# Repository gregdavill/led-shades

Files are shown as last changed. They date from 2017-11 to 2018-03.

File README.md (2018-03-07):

# ledShades

*Simple Arduino compatible RGB LED shades. Using an absurd quantinty of APA102 2020 smart LEDs.*

## 3d Render

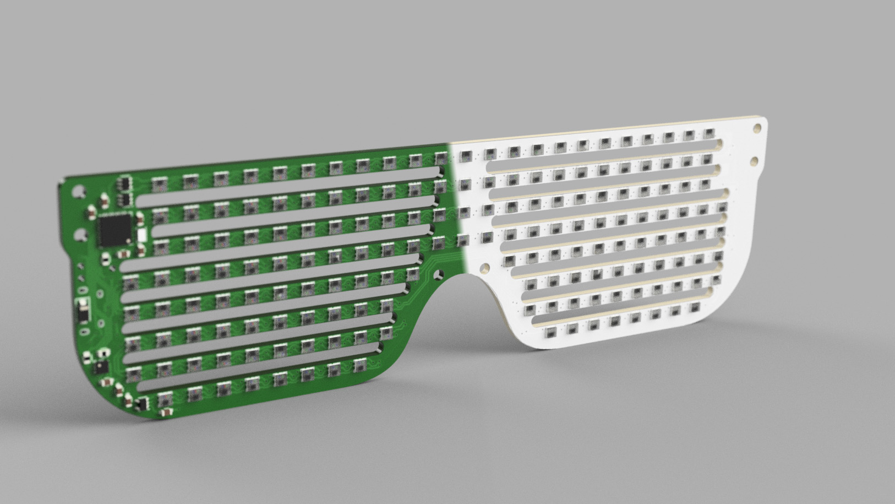
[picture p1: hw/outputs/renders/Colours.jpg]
led-shades Render


When deciding between green and white PCBs I created this render. I ended up using white PCBs for my prototypes. Black would also look good.

---

## Schematic

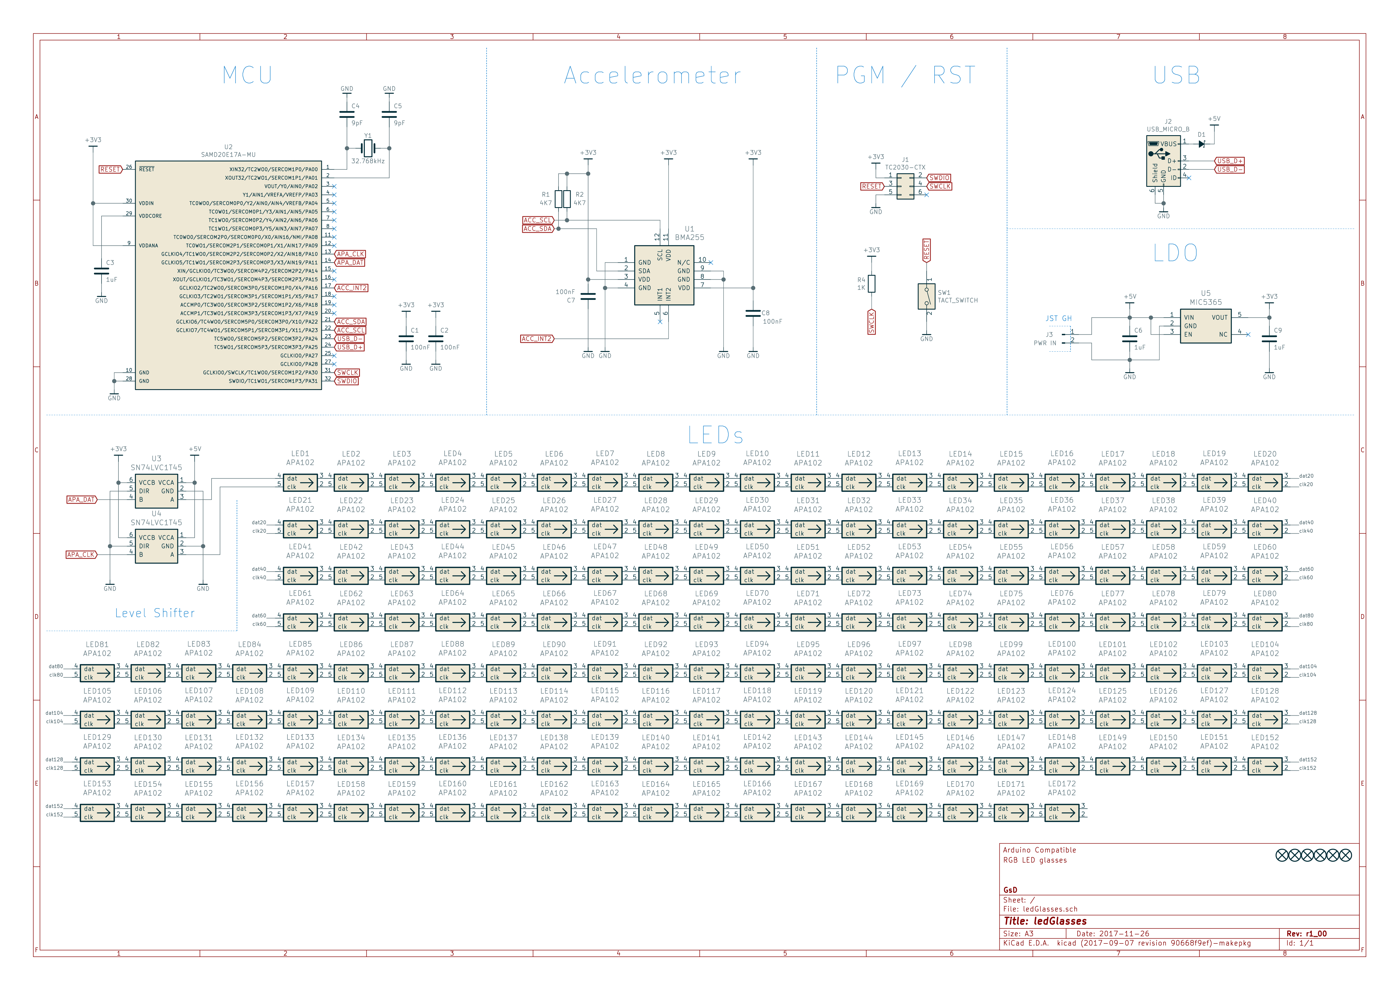
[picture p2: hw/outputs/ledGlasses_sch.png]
led-shades Schematic


Schematic is quite simple. The ATSAMD21 is loaded with the Arduino bootloader and programmed with FastLED to control the single array of 173 APA102 LEDs. Due to the voltage difference between the D21 and the APA102's I used two logic level converters for the clock and data lines.

---

## PCB

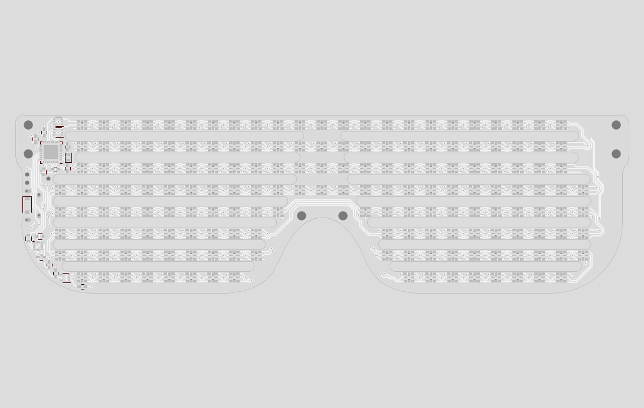
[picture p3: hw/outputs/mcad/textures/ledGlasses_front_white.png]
led-shades PCB


PCB was designed in KiCad and is a mostly single sided load. (Power connector, solders to back). The PCB is designed to act as the frame of the glasses directly. Some 3d printed arms are fitted to the edges of the glasses in older to attach them to your face.

---

## Firmware

The firmawre for the device is found in the fw folder. It is buil/t with the arduino IDE with 2 external libraries

* Adafruit GFX
* FastLED

The included code provides a simple wrapper to connect these libraries together to control the screen. Some small changes need to be made in orlder to accomadate good quality RGB data to the LEDs this includes changing the colour parameter in the GFX library to uint32_t type.

The main code supports 4 different modes of operation. Switching between modes is achieved by tapping the right side of the glasses. This triggers a tap event with the accelorometer.

## Development Timeline

* [x] Concept
* [x] Schematic
* [x] PCB Layout
* [x] 3d CAD export/cleanup
* [x] BOM export
* [x] Prototypes assembled
* [x] Firmware buildup
* [x] Additional Documentation
* [x] Small Volume Run

## License

MIT - See [LICENCE](LICENSE)

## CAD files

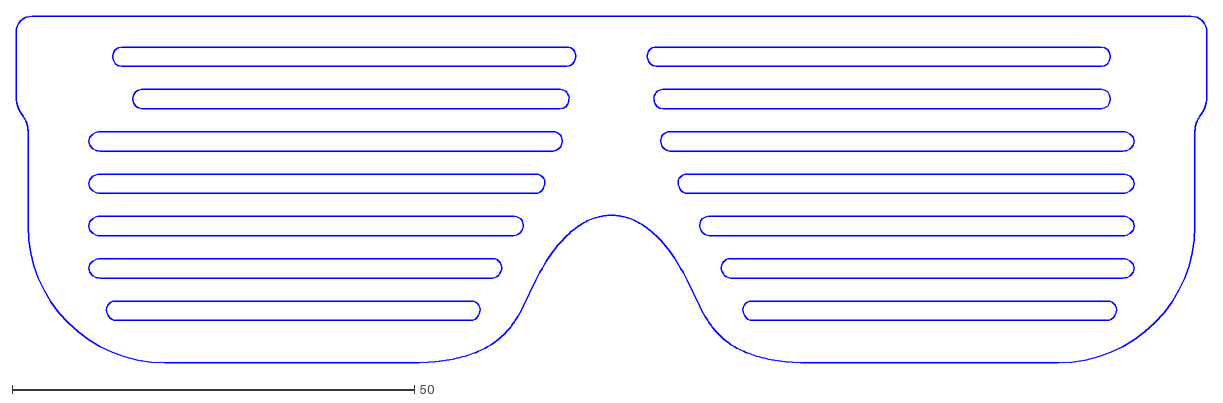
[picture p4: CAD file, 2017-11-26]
hw/ref/PCB outline.dxf
148.1 x 43.1

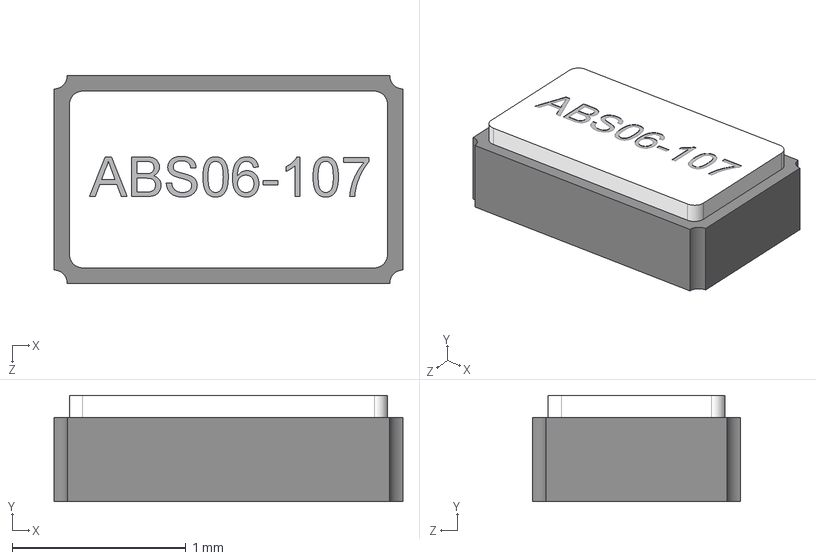
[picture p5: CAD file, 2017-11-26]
hw/ref/ABS06-107.STEP
2.01 x 0.612 x 1.19 mm

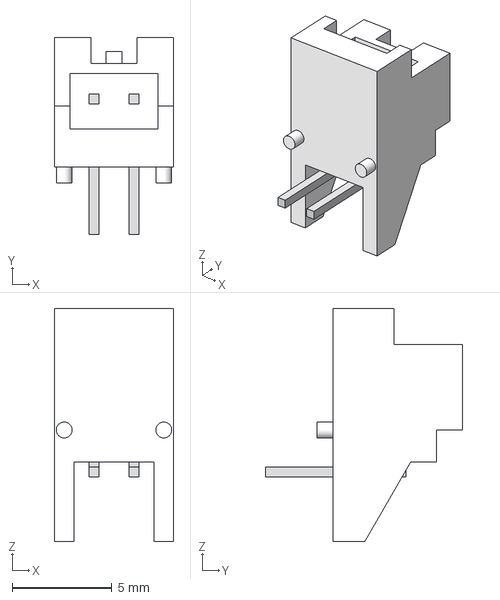
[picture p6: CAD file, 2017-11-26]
hw/ref/S02B-PASK-2.step
6.00 x 9.90 x 11.7 mm

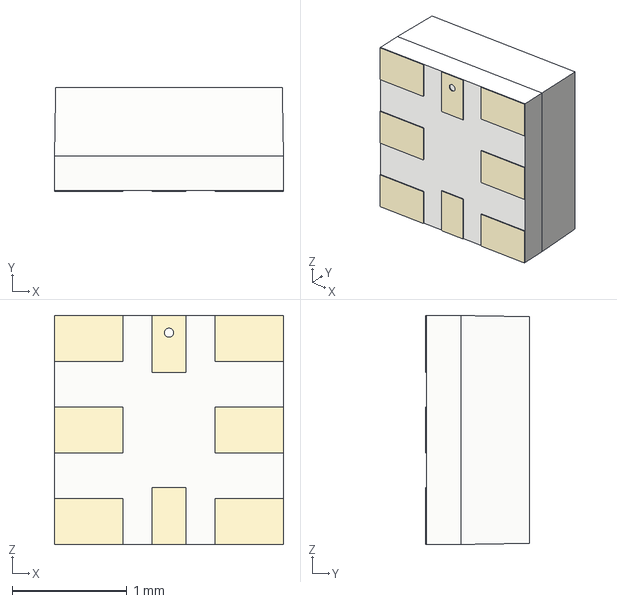
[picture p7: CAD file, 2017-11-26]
hw/ref/APA102 2020 LED.step
2.00 x 0.91 x 2.00 mm

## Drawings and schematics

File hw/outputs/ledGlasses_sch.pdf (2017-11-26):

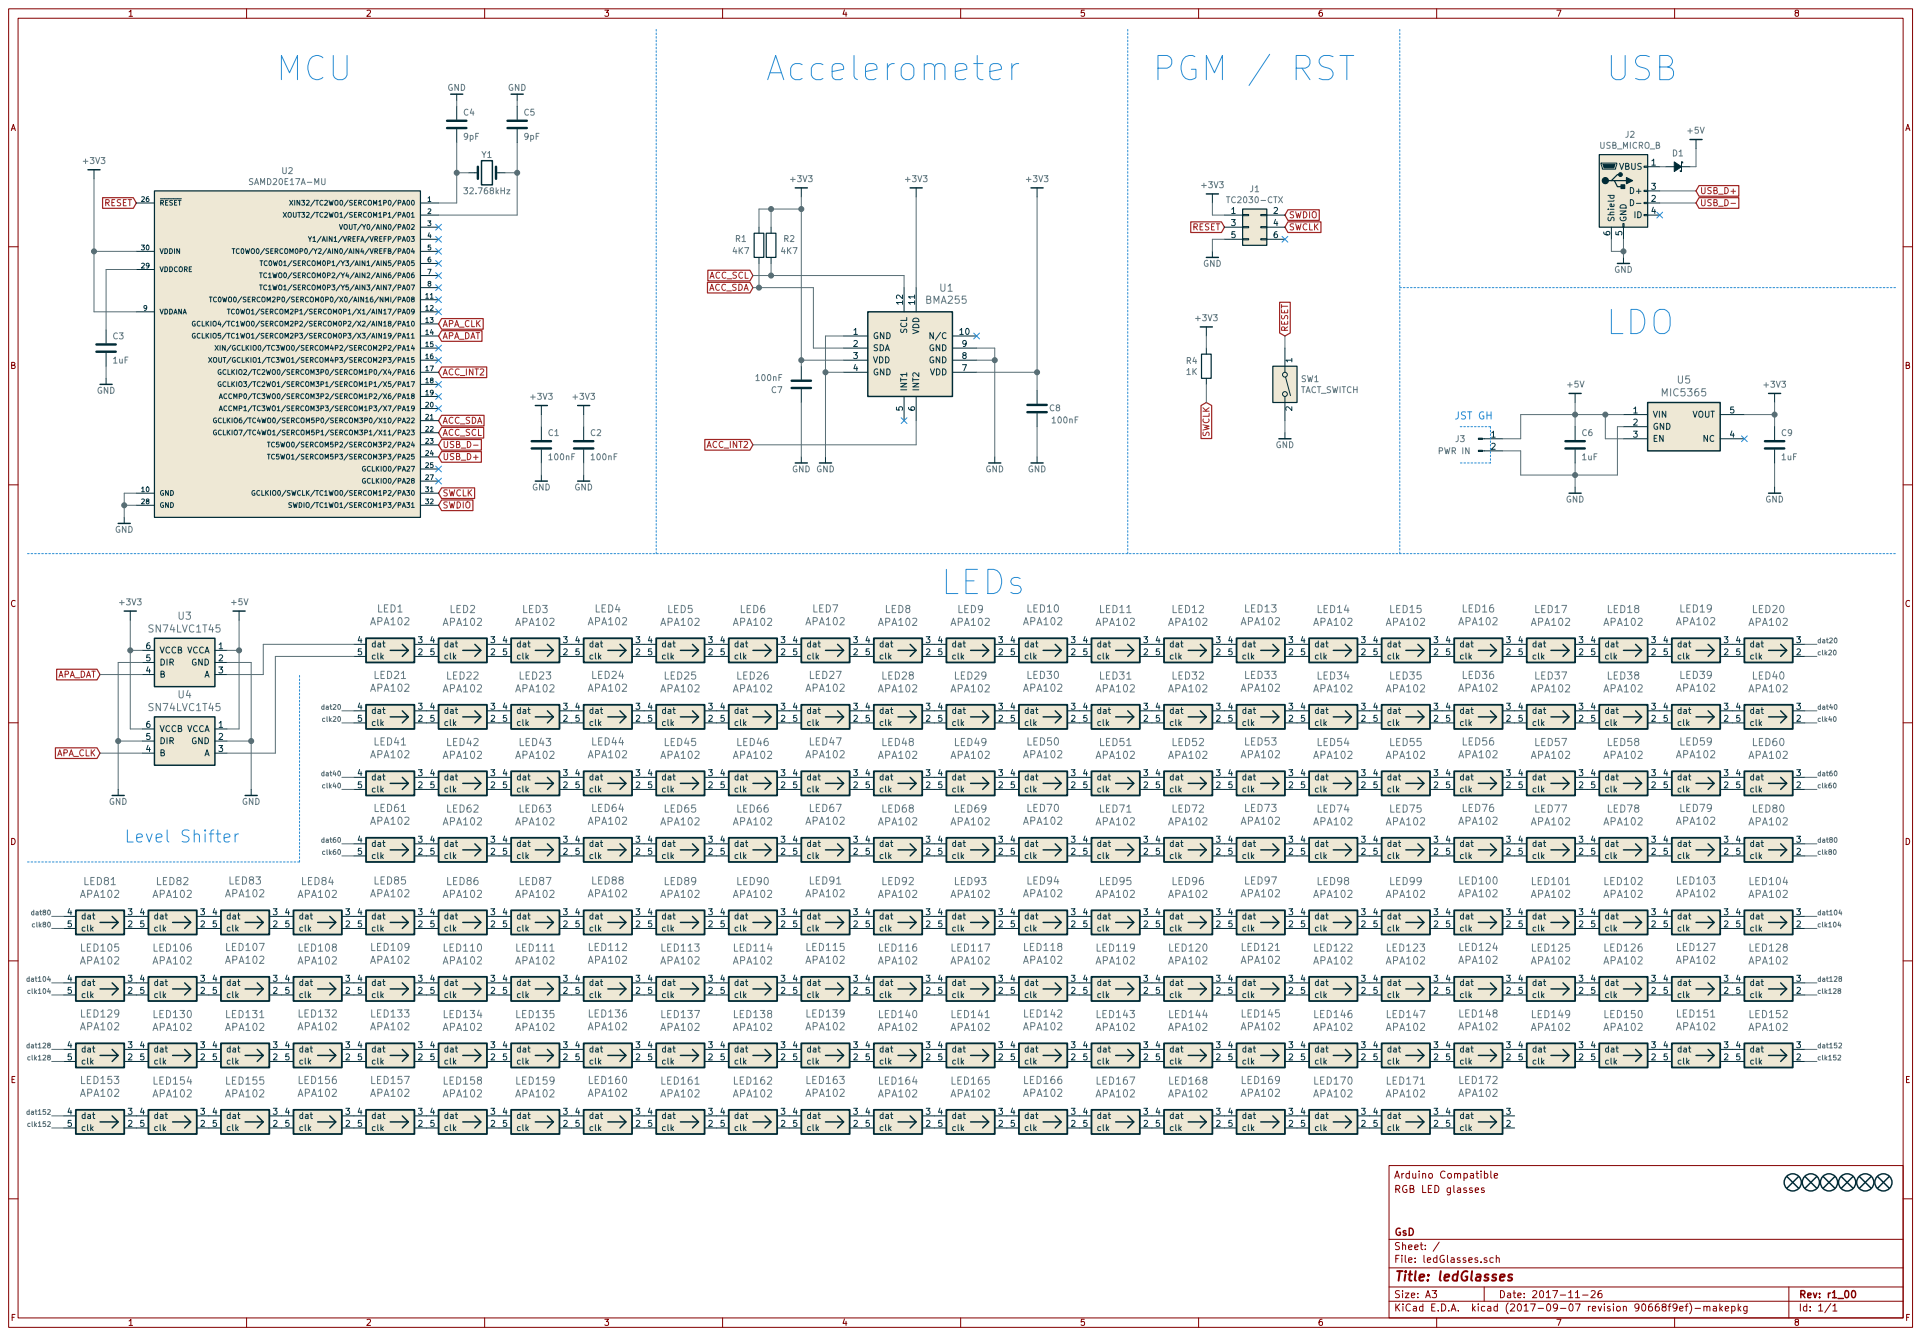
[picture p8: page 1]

6 VDD 7 GND 8 GND 9 N/C VDD 10 11 SCL 12 U1 BMA255

J3 PWR IN Level Shifter

File: ledGlasses.sch Sheet: / GsD

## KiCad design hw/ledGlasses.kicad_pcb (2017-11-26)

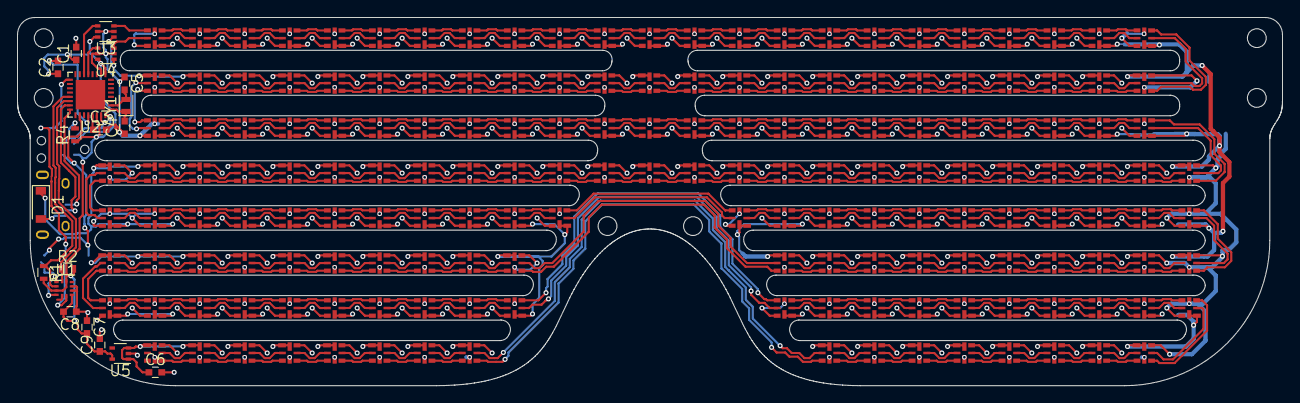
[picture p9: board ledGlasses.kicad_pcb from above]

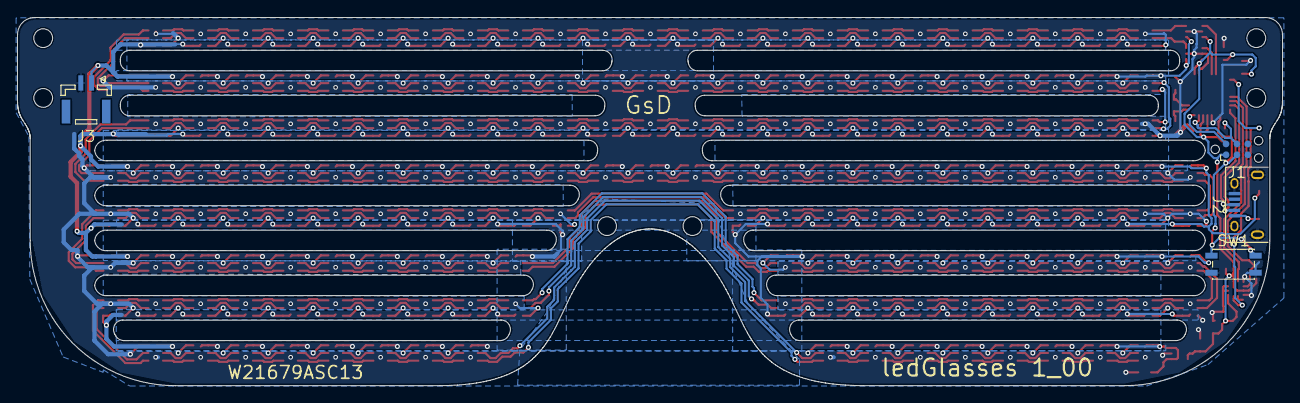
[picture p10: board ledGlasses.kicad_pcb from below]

Board: 2 copper layers, 148.1 x 43.1 mm, 201 parts (4 on the bottom side), 361 nets.

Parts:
C1, C2, C7, C8: 100nF; C_0603
C3, C6, C9: 1uF; C_0603
C4, C5: 16pF; C_0603
D1: Diode; D_SOD-123
J1: TC2030-CTX; Tag-Connect_TC2030-IDC-NL
J2: USB_OTG; USB_Micro-B
J3: PWR IN; JST_GH_BM02B-GHS-TBT_02x1.25mm_Straight
LED1, LED2, LED3, LED4, LED5, LED6, LED7, LED8, LED9, LED10, LED11, LED12, LED13, LED14, LED15, LED16, LED17, LED18, LED19, LED20, LED21, LED22, LED23, LED24, LED25, LED26, LED27, LED28, LED29, LED30, LED31, LED32, LED33, LED34, LED35, LED36, LED37, LED38, LED39, LED40, LED41, LED42, LED43, LED44, LED45, LED46, LED47, LED48, LED49, LED50, LED51, LED52, LED53, LED54, LED55, LED56, LED57, LED58, LED59, LED60, LED61, LED62, LED63, LED64, LED65, LED66, LED67, LED68, LED69, LED70, LED71, LED72, LED73, LED74, LED75, LED76, LED77, LED78, LED79, LED80, LED81, LED82, LED83, LED84, LED85, LED86, LED87, LED88, LED89, LED90, LED91, LED92, LED93, LED94, LED95, LED96, LED97, LED98, LED99, LED100, LED101, LED102, LED103, LED104, LED105, LED106, LED107, LED108, LED109, LED110, LED111, LED112, LED113, LED114, LED115, LED116, LED117, LED118, LED119, LED120, LED121, LED122, LED123, LED124, LED125, LED126, LED127, LED128, LED129, LED130, LED131, LED132, LED133, LED134, LED135, LED136, LED137, LED138, LED139, LED140, LED141, LED142, LED143, LED144, LED145, LED146, LED147, LED148, LED149, LED150, LED151, LED152, LED153, LED154, LED155, LED156, LED157, LED158, LED159, LED160, LED161, LED162, LED163, LED164, LED165, LED166, LED167, LED168, LED169, LED170, LED171, LED172: APA102; APA102_2020
MH1, MH2, MH3, MH4, MH5, MH6: MountingHole; MountingHole_2.2mm_M2_DIN965
R1, R2: 4K7; R_0603
R4: 1K; R_0603
SW1: TACT_SWITCH; SW_SPST_EVQP2
U1: BMA255
U2: SAMD20E17A-MU; QFN-32-1EP_5x5mm_Pitch0.5mm
U3, U4: SN74LVC1T45; SOT-363_SC-70-6
U5: MIC5365; SOT-353_SC-70-5
Y1: 32.768kHz; Crystal_SMD_2012-2pin_2.0x1.2mm

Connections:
+3V3: C1.1, C2.1, C7.2, C8.2, C9.1, J1.1, R1.2, R2.2, R4.1, U1.3, U1.7, U1.11, U2.9, U2.30, U3.6, U4.6, U5.5
+5V: C6.1, D1.1, J3.1, LED1.1, LED1.7, LED2.1, LED2.7, LED3.1, LED3.7, LED4.1, LED4.7, LED5.1, LED5.7, LED6.1, LED6.7, LED7.1, LED7.7, LED8.1, LED8.7, LED9.1, LED9.7, LED10.1, LED10.7, LED11.1, LED11.7, LED12.1, LED12.7, LED13.1, LED13.7, LED14.1, LED14.7, LED15.1, LED15.7, LED16.1, LED16.7, LED17.1, LED17.7, LED18.1, LED18.7, LED19.1, LED19.7, LED20.1, LED20.7, LED21.1, LED21.7, LED22.1, LED22.7, LED23.1, LED23.7, LED24.1, LED24.7, LED25.1, LED25.7, LED26.1, LED26.7, LED27.1, LED27.7, LED28.1, LED28.7, LED29.1, LED29.7, LED30.1, LED30.7, LED31.1, LED31.7, LED32.1, LED32.7, LED33.1, LED33.7, LED34.1, LED34.7, LED35.1, LED35.7, LED36.1, LED36.7, LED37.1, LED37.7, LED38.1, LED38.7, LED39.1, LED39.7, LED40.1, LED40.7, LED41.1, LED41.7, LED42.1, LED42.7, LED43.1, LED43.7, LED44.1, LED44.7, LED45.1, LED45.7, LED46.1, LED46.7, LED47.1, LED47.7, LED48.1, LED48.7, LED49.1, LED49.7, LED50.1, LED50.7, LED51.1, LED51.7, LED52.1, LED52.7, LED53.1, LED53.7, LED54.1, LED54.7, LED55.1, LED55.7, LED56.1, LED56.7, LED57.1, LED57.7, LED58.1, LED58.7, LED59.1, LED59.7, LED60.1, LED60.7, LED61.1, LED61.7, LED62.1, LED62.7, LED63.1, LED63.7, LED64.1, LED64.7, LED65.1, LED65.7, LED66.1, LED66.7, LED67.1, LED67.7, LED68.1, LED68.7, LED69.1, LED69.7, LED70.1, LED70.7, LED71.1, LED71.7, LED72.1, LED72.7, LED73.1, LED73.7, LED74.1, LED74.7, LED75.1, LED75.7, LED76.1, LED76.7, LED77.1, LED77.7, LED78.1, LED78.7, LED79.1, LED79.7, LED80.1, LED80.7, LED81.1, LED81.7, LED82.1, LED82.7, LED83.1, LED83.7, LED84.1, LED84.7, LED85.1, LED85.7, LED86.1, LED86.7, LED87.1, LED87.7, LED88.1, LED88.7, LED89.1, LED89.7, LED90.1, LED90.7, LED91.1, LED91.7, LED92.1, LED92.7, LED93.1, LED93.7, LED94.1, LED94.7, LED95.1, LED95.7, LED96.1, LED96.7, LED97.1, LED97.7, LED98.1, LED98.7, LED99.1, LED99.7, LED100.1, LED100.7, LED101.1, LED101.7, LED102.1, LED102.7, LED103.1, LED103.7, LED104.1, LED104.7, LED105.1, LED105.7, LED106.1, LED106.7, LED107.1, LED107.7, LED108.1, LED108.7, LED109.1, LED109.7, LED110.1, LED110.7, LED111.1, LED111.7, LED112.1, LED112.7, LED113.1, LED113.7, LED114.1, LED114.7, LED115.1, LED115.7, LED116.1, LED116.7, LED117.1, LED117.7, LED118.1, LED118.7, LED119.1, LED119.7, LED120.1, LED120.7, LED121.1, LED121.7, LED122.1, LED122.7, LED123.1, LED123.7, LED124.1, LED124.7, LED125.1, LED125.7, LED126.1, LED126.7, LED127.1, LED127.7, LED128.1, LED128.7, LED129.1, LED129.7, LED130.1, LED130.7, LED131.1, LED131.7, LED132.1, LED132.7, LED133.1, LED133.7, LED134.1, LED134.7, LED135.1, LED135.7, LED136.1, LED136.7, LED137.1, LED137.7, LED138.1, LED138.7, LED139.1, LED139.7, LED140.1, LED140.7, LED141.1, LED141.7, LED142.1, LED142.7, LED143.1, LED143.7, LED144.1, LED144.7, LED145.1, LED145.7, LED146.1, LED146.7, LED147.1, LED147.7, LED148.1, LED148.7, LED149.1, LED149.7, LED150.1, LED150.7, LED151.1, LED151.7, LED152.1, LED152.7, LED153.1, LED153.7, LED154.1, LED154.7, LED155.1, LED155.7, LED156.1, LED156.7, LED157.1, LED157.7, LED158.1, LED158.7, LED159.1, LED159.7, LED160.1, LED160.7, LED161.1, LED161.7, LED162.1, LED162.7, LED163.1, LED163.7, LED164.1, LED164.7, LED165.1, LED165.7, LED166.1, LED166.7, LED167.1, LED167.7, LED168.1, LED168.7, LED169.1, LED169.7, LED170.1, LED170.7, LED171.1, LED171.7, LED172.1, LED172.7, U3.1, U4.1, U5.1, U5.3
/clk20: LED20.2, LED21.5
/clk40: LED40.2, LED41.5
/clk60: LED60.2, LED61.5
/clk80: LED80.2, LED81.5
/clk104: LED104.2, LED105.5
/clk128: LED128.2, LED129.5
/clk152: LED152.2, LED153.5
/dat20: LED20.3, LED21.4
/dat40: LED40.3, LED41.4
/dat60: LED60.3, LED61.4
/dat80: LED80.3, LED81.4
/dat104: LED104.3, LED105.4
/dat128: LED128.3, LED129.4
/dat152: LED152.3, LED153.4
ACC_INT2: U1.6, U2.17
ACC_SCL: R2.1, U1.12, U2.22
ACC_SDA: R1.1, U1.2, U2.21
APA_CLK: U2.13, U4.4
APA_DAT: U2.14, U3.4
GND: C1.2, C2.2, C3.2, C4.1, C5.1, C6.2, C7.1, C8.1, C9.2, J1.5, J2.5, J2.6, J3.2, LED1.6, LED1.8, LED2.6, LED2.8, LED3.6, LED3.8, LED4.6, LED4.8, LED5.6, LED5.8, LED6.6, LED6.8, LED7.6, LED7.8, LED8.6, LED8.8, LED9.6, LED9.8, LED10.6, LED10.8, LED11.6, LED11.8, LED12.6, LED12.8, LED13.6, LED13.8, LED14.6, LED14.8, LED15.6, LED15.8, LED16.6, LED16.8, LED17.6, LED17.8, LED18.6, LED18.8, LED19.6, LED19.8, LED20.6, LED20.8, LED21.6, LED21.8, LED22.6, LED22.8, LED23.6, LED23.8, LED24.6, LED24.8, LED25.6, LED25.8, LED26.6, LED26.8, LED27.6, LED27.8, LED28.6, LED28.8, LED29.6, LED29.8, LED30.6, LED30.8, LED31.6, LED31.8, LED32.6, LED32.8, LED33.6, LED33.8, LED34.6, LED34.8, LED35.6, LED35.8, LED36.6, LED36.8, LED37.6, LED37.8, LED38.6, LED38.8, LED39.6, LED39.8, LED40.6, LED40.8, LED41.6, LED41.8, LED42.6, LED42.8, LED43.6, LED43.8, LED44.6, LED44.8, LED45.6, LED45.8, LED46.6, LED46.8, LED47.6, LED47.8, LED48.6, LED48.8, LED49.6, LED49.8, LED50.6, LED50.8, LED51.6, LED51.8, LED52.6, LED52.8, LED53.6, LED53.8, LED54.6, LED54.8, LED55.6, LED55.8, LED56.6, LED56.8, LED57.6, LED57.8, LED58.6, LED58.8, LED59.6, LED59.8, LED60.6, LED60.8, LED61.6, LED61.8, LED62.6, LED62.8, LED63.6, LED63.8, LED64.6, LED64.8, LED65.6, LED65.8, LED66.6, LED66.8, LED67.6, LED67.8, LED68.6, LED68.8, LED69.6, LED69.8, LED70.6, LED70.8, LED71.6, LED71.8, LED72.6, LED72.8, LED73.6, LED73.8, LED74.6, LED74.8, LED75.6, LED75.8, LED76.6, LED76.8, LED77.6, LED77.8, LED78.6, LED78.8, LED79.6, LED79.8, LED80.6, LED80.8, LED81.6, LED81.8, LED82.6, LED82.8, LED83.6, LED83.8, LED84.6, LED84.8, LED85.6, LED85.8, LED86.6, LED86.8, LED87.6, LED87.8, LED88.6, LED88.8, LED89.6, LED89.8, LED90.6, LED90.8, LED91.6, LED91.8, LED92.6, LED92.8, LED93.6, LED93.8, LED94.6, LED94.8, LED95.6, LED95.8, LED96.6, LED96.8, LED97.6, LED97.8, LED98.6, LED98.8, LED99.6, LED99.8, LED100.6, LED100.8, LED101.6, LED101.8, LED102.6, LED102.8, LED103.6, LED103.8, LED104.6, LED104.8, LED105.6, LED105.8, LED106.6, LED106.8, LED107.6, LED107.8, LED108.6, LED108.8, LED109.6, LED109.8, LED110.6, LED110.8, LED111.6, LED111.8, LED112.6, LED112.8, LED113.6, LED113.8, LED114.6, LED114.8, LED115.6, LED115.8, LED116.6, LED116.8, LED117.6, LED117.8, LED118.6, LED118.8, LED119.6, LED119.8, LED120.6, LED120.8, LED121.6, LED121.8, LED122.6, LED122.8, LED123.6, LED123.8, LED124.6, LED124.8, LED125.6, LED125.8, LED126.6, LED126.8, LED127.6, LED127.8, LED128.6, LED128.8, LED129.6, LED129.8, LED130.6, LED130.8, LED131.6, LED131.8, LED132.6, LED132.8, LED133.6, LED133.8, LED134.6, LED134.8, LED135.6, LED135.8, LED136.6, LED136.8, LED137.6, LED137.8, LED138.6, LED138.8, LED139.6, LED139.8, LED140.6, LED140.8, LED141.6, LED141.8, LED142.6, LED142.8, LED143.6, LED143.8, LED144.6, LED144.8, LED145.6, LED145.8, LED146.6, LED146.8, LED147.6, LED147.8, LED148.6, LED148.8, LED149.6, LED149.8, LED150.6, LED150.8, LED151.6, LED151.8, LED152.6, LED152.8, LED153.6, LED153.8, LED154.6, LED154.8, LED155.6, LED155.8, LED156.6, LED156.8, LED157.6, LED157.8, LED158.6, LED158.8, LED159.6, LED159.8, LED160.6, LED160.8, LED161.6, LED161.8, LED162.6, LED162.8, LED163.6, LED163.8, LED164.6, LED164.8, LED165.6, LED165.8, LED166.6, LED166.8, LED167.6, LED167.8, LED168.6, LED168.8, LED169.6, LED169.8, LED170.6, LED170.8, LED171.6, LED171.8, LED172.6, LED172.8, SW1.2, U1.1, U1.4, U1.8, U1.9, U2.10, U2.28, U3.2, U3.5, U4.2, U4.5, U5.2
unnamed: C3.1, U2.29
unnamed: C4.2, U2.1, Y1.1
unnamed: C5.2, U2.2, Y1.2
unnamed: D1.2, J2.1
unnamed: LED1.2, LED2.5
unnamed: LED1.3, LED2.4
unnamed: LED1.4, U3.3
unnamed: LED1.5, U4.3
unnamed: LED2.2, LED3.5
unnamed: LED2.3, LED3.4
unnamed: LED3.2, LED4.5
unnamed: LED3.3, LED4.4
unnamed: LED4.2, LED5.5
unnamed: LED4.3, LED5.4
unnamed: LED5.2, LED6.5
unnamed: LED5.3, LED6.4
unnamed: LED6.2, LED7.5
unnamed: LED6.3, LED7.4
unnamed: LED7.2, LED8.5
unnamed: LED7.3, LED8.4
unnamed: LED8.2, LED9.5
unnamed: LED8.3, LED9.4
unnamed: LED10.2, LED11.5
unnamed: LED10.3, LED11.4
unnamed: LED9.3, LED10.4
unnamed: LED9.2, LED10.5
unnamed: LED11.2, LED12.5
unnamed: LED11.3, LED12.4
unnamed: LED12.2, LED13.5
unnamed: LED12.3, LED13.4
unnamed: LED13.2, LED14.5
unnamed: LED13.3, LED14.4
unnamed: LED14.2, LED15.5
unnamed: LED14.3, LED15.4
unnamed: LED15.2, LED16.5
unnamed: LED15.3, LED16.4
unnamed: LED16.2, LED17.5
unnamed: LED16.3, LED17.4
unnamed: LED17.2, LED18.5
unnamed: LED17.3, LED18.4
unnamed: LED18.2, LED19.5
unnamed: LED18.3, LED19.4
unnamed: LED19.2, LED20.5
unnamed: LED19.3, LED20.4
unnamed: LED21.2, LED22.5
unnamed: LED21.3, LED22.4
unnamed: LED22.2, LED23.5
unnamed: LED22.3, LED23.4
unnamed: LED23.2, LED24.5
unnamed: LED23.3, LED24.4
unnamed: LED24.2, LED25.5
unnamed: LED24.3, LED25.4
unnamed: LED25.2, LED26.5
unnamed: LED25.3, LED26.4
unnamed: LED26.2, LED27.5
unnamed: LED26.3, LED27.4
unnamed: LED27.2, LED28.5
unnamed: LED27.3, LED28.4
unnamed: LED28.2, LED29.5
unnamed: LED28.3, LED29.4
unnamed: LED29.2, LED30.5
unnamed: LED29.3, LED30.4
unnamed: LED30.2, LED31.5
unnamed: LED30.3, LED31.4
unnamed: LED31.2, LED32.5
unnamed: LED31.3, LED32.4
unnamed: LED32.2, LED33.5
unnamed: LED32.3, LED33.4
unnamed: LED33.2, LED34.5
unnamed: LED33.3, LED34.4
unnamed: LED34.2, LED35.5
unnamed: LED34.3, LED35.4
unnamed: LED35.2, LED36.5
unnamed: LED35.3, LED36.4
unnamed: LED36.2, LED37.5
unnamed: LED36.3, LED37.4
unnamed: LED37.2, LED38.5
unnamed: LED37.3, LED38.4
unnamed: LED38.2, LED39.5
unnamed: LED38.3, LED39.4
unnamed: LED39.2, LED40.5
unnamed: LED39.3, LED40.4
unnamed: LED41.2, LED42.5
unnamed: LED41.3, LED42.4
unnamed: LED42.2, LED43.5
unnamed: LED42.3, LED43.4
unnamed: LED43.2, LED44.5
unnamed: LED43.3, LED44.4
unnamed: LED44.2, LED45.5
unnamed: LED44.3, LED45.4
unnamed: LED45.2, LED46.5
unnamed: LED45.3, LED46.4
unnamed: LED46.2, LED47.5
unnamed: LED46.3, LED47.4
unnamed: LED47.2, LED48.5
unnamed: LED47.3, LED48.4
unnamed: LED48.2, LED49.5
unnamed: LED48.3, LED49.4
unnamed: LED49.2, LED50.5
unnamed: LED49.3, LED50.4
unnamed: LED50.2, LED51.5
unnamed: LED50.3, LED51.4
unnamed: LED51.2, LED52.5
unnamed: LED51.3, LED52.4
unnamed: LED52.2, LED53.5
unnamed: LED52.3, LED53.4
unnamed: LED53.2, LED54.5
unnamed: LED53.3, LED54.4
unnamed: LED54.2, LED55.5
unnamed: LED54.3, LED55.4
unnamed: LED55.2, LED56.5
unnamed: LED55.3, LED56.4
unnamed: LED56.2, LED57.5
unnamed: LED56.3, LED57.4
unnamed: LED57.2, LED58.5
unnamed: LED57.3, LED58.4
unnamed: LED58.2, LED59.5
unnamed: LED58.3, LED59.4
unnamed: LED59.2, LED60.5
unnamed: LED59.3, LED60.4
unnamed: LED61.2, LED62.5
unnamed: LED61.3, LED62.4
unnamed: LED62.2, LED63.5
unnamed: LED62.3, LED63.4
unnamed: LED63.2, LED64.5
unnamed: LED63.3, LED64.4
unnamed: LED64.2, LED65.5
unnamed: LED64.3, LED65.4
unnamed: LED65.2, LED66.5
unnamed: LED65.3, LED66.4
unnamed: LED66.2, LED67.5
unnamed: LED66.3, LED67.4
unnamed: LED67.2, LED68.5
unnamed: LED67.3, LED68.4
unnamed: LED68.2, LED69.5
unnamed: LED68.3, LED69.4
unnamed: LED69.2, LED70.5
unnamed: LED69.3, LED70.4
unnamed: LED70.2, LED71.5
unnamed: LED70.3, LED71.4
unnamed: LED71.2, LED72.5
unnamed: LED71.3, LED72.4
unnamed: LED72.2, LED73.5
unnamed: LED72.3, LED73.4
unnamed: LED73.2, LED74.5
unnamed: LED73.3, LED74.4
unnamed: LED74.2, LED75.5
unnamed: LED74.3, LED75.4
unnamed: LED75.2, LED76.5
unnamed: LED75.3, LED76.4
unnamed: LED76.2, LED77.5
unnamed: LED76.3, LED77.4
unnamed: LED77.2, LED78.5
unnamed: LED77.3, LED78.4
unnamed: LED78.2, LED79.5
unnamed: LED78.3, LED79.4
unnamed: LED79.2, LED80.5
unnamed: LED79.3, LED80.4
unnamed: LED81.2, LED82.5
unnamed: LED81.3, LED82.4
unnamed: LED82.2, LED83.5
unnamed: LED82.3, LED83.4
unnamed: LED83.2, LED84.5
unnamed: LED83.3, LED84.4
unnamed: LED84.2, LED85.5
unnamed: LED84.3, LED85.4
unnamed: LED85.2, LED86.5
unnamed: LED85.3, LED86.4
unnamed: LED86.2, LED87.5
unnamed: LED86.3, LED87.4
unnamed: LED87.2, LED88.5
unnamed: LED87.3, LED88.4
unnamed: LED88.2, LED89.5
unnamed: LED88.3, LED89.4
unnamed: LED89.2, LED90.5
unnamed: LED89.3, LED90.4
unnamed: LED90.2, LED91.5
unnamed: LED90.3, LED91.4
unnamed: LED91.2, LED92.5
unnamed: LED91.3, LED92.4
unnamed: LED92.2, LED93.5
unnamed: LED92.3, LED93.4
unnamed: LED93.2, LED94.5
unnamed: LED93.3, LED94.4
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

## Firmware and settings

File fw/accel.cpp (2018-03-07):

#include "accel.h"
#include <Arduino.h>
#include <Wire.h>

void accelInit()
{
    uint8_t buffer[2] = {0x21, 0x01};

    Wire.begin();

    buffer[0] = 0x20;
    buffer[1] = 0x04;
    Wire.beginTransmission(0x18);
    Wire.write(buffer, 2); /* Active high INT pins */
    Wire.endTransmission();

    buffer[0] = 0x1B;
    buffer[1] = 0x20;
    Wire.beginTransmission(0x18);
    Wire.write(buffer, 2); /* Active Double Tap on INT2 */
    Wire.endTransmission();

    buffer[0] = 0x16;
    buffer[1] = 0x20;
    Wire.beginTransmission(0x18);
    Wire.write(buffer, 2); /* Enable Double Tap feature */
    Wire.endTransmission();

    buffer[0] = 0x1E;
    buffer[1] = 0x00;
    Wire.beginTransmission(0x18);
    Wire.write(buffer, 2); /* Enable filtered data to tap detection */
    Wire.endTransmission();

    buffer[0] = 0x2A;
    buffer[1] = 0xC7;
    Wire.beginTransmission(0x18);
    Wire.write(buffer, 2); /* Set Tap detection params */
    Wire.endTransmission();

    buffer[0] = 0x0F;
    buffer[1] = 0x03;
    Wire.beginTransmission(0x18);
    Wire.write(buffer, 2); /* Set 2G range */
    Wire.endTransmission();

    accelResetIntLatch();

    pinMode(11, INPUT_PULLUP);
}

void accelResetIntLatch()
{
    return;
    uint8_t buffer[2] = {0x21, 0x80};

    Wire.beginTransmission(0x18);
    Wire.write(buffer, 2);
    Wire.endTransmission();
}

bool accelReadIntPin()
{
    uint8_t buffer[1] = {0x09};
    Wire.beginTransmission(0x18);
    Wire.write(buffer, 1);
    Wire.endTransmission();
    Wire.requestFrom(0x18, 3);
    uint8_t data = Wire.read();
    uint8_t extrainfo = Wire.read();
    uint8_t tapDir = Wire.read();

    static uint32_t timeout = 0;

    /* Check a register and if we have not recently changed modes change. */
    if (tapDir & 0x20) {
        if ((millis() - timeout) > 500) {
            timeout = millis();
            return 1;
        }
    }

    return 0;
}

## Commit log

2017-11-26 Added PCB files.
    [ABS06-107.STEP, APA102 2020 LED.step, PCB outline.dxf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]
2018-03-07 Added inital fw for project.
    [ABS06-107.STEP, APA102 2020 LED.step, PCB outline.dxf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]
